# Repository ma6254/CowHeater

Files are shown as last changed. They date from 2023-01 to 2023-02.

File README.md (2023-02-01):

# CowHeater

[[主控板PCB介绍]](pcb_mb/README.md) [[主控板代码介绍]](src_mb/README.md)

CowHeater 是一个开源的加热台，不便携。

目标在于实现一种比较通用的加热器件控制器，
同时学习可控硅控制、热电偶温度采集、PID等电子技术。

- 主控：STC8H8K64U(TSSOP-20)
- 供电方式：ACDC 集成模块
- 控制方式：可控硅斩波调功率
- 温度采集方式：K型热电偶+运放

system block diagram

## 购买元器件

在[立创商城BOM配单](https://bom.szlcsc.com/bom/upload.html)即可，BOM文件位于[docs/BOM_for_LCSC.csv](docs/BOM_for_LCSC.csv)

注意：

- 海凌科的电源模块长期无现货，在淘宝上购买
- 用到的STC单片机长期无现货，在淘宝上购买
- 运放和可控硅尽量在立创商城上买，淘宝假货太多了

## 进度表

1. `2023-01-06` 打算做个加热台的项目
   - PCB_V01 随便拉了线，发去嘉立创打样了
   - 淘宝和立创商城上买了一堆器件
   - 买了某仙子的PTC，后面再搞高温的MCH发热板吧
2. `2023-01-08` 等快递ing
   - BUG: 发热板热量会通过铜柱传导到PCB上面，后面需要解决
   - 靠，立创商城下单数量错了，STC单片机只买了一片
   - 靠，PCB打样的收件地址写错了，写成了上家公司，让同事寄过来了
   - 靠，烧录口没引出来，还得割线飞线
   - 有几个包裹是圆通的，还没配送
3. `2023-01-12` 快递到了，开始调试
   - 可控硅导通不了，R10改为360Ω，增加R13为330Ω
   - 电源模块封装不对，实物整体往右偏1.5mm
4. `2023-02-01` 改了板子，重新发出去打样
   - PCB_V02
   - PCB_V03
   - 电源模块从 `HLK-2M05` 换成了 `HLK-5M05`
   - 干哦，可控硅电路还是没有调通，发现是12脚反了

## 参考资料

### STC开发资料

- STC8H数据手册: <http://www.stcmcudata.com/STC8F-DATASHEET/STC8H.pdf>
  - P.72: STC8H8K64U-TSSOP20引脚定义
- STC-ISP下载链接: <http://www.stcmcudata.com/STCISP/stc-isp-15xx-v6.91I.zip>
- STC命令行烧录软件 stcflash: <https://github.com/sms-wyt/stcflash>

### 海凌科电源模块资料

- [HLK-2M05/2M03/2M09/2M12/2M24 2W系列AC-DC电源模块](<https://www.hlktech.com/Goods-39.html>)
- [海凌科2W系列电源模块说明书V2.6.pdf](http://r0.hlktech.com/download/ACDC%E7%94%B5%E6%BA%90%E6%A8%A1%E5%9D%972W%E7%B3%BB%E5%88%97/1/%E6%B5%B7%E5%87%8C%E7%A7%912W%E7%B3%BB%E5%88%97%E7%94%B5%E6%BA%90%E6%A8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)

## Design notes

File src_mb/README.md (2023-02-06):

# Source CowHeater_MB

芯片: `STC8H8K64U`(`TSSOP20`)

烧录文件: [`Objects/cowheater_mb.hex`](Objects/cowheater_mb.hex)

## 引脚定义

| Name | Pin | GPIO | Description |
| --- | --- | --- | --- |
| LED | 5 | P13 | 测试用的，接LED负极 |
| UART1_RX | 11  | P30/RxD  | STC-ISP烧录口，UART1_RX |
| UART1_TX | 12  | P31/TxD  | STC-ISP烧录口，UART1_TX |
| I2C_SCL  | 2 | P15 | 预留，接I2C器件SCL |
| I2C_SDA  | 1 | P14 | 预留，接I2C器件SDA |
| HEAT | 20  | P10 | 可控硅控制脚 |
| TEMP | 19  | P11/ADC1 | 热床温度，热电偶信号采样脚 |

## 目录

```plaintext
├─.vscode             # VSCode配置
├─Objects             # 编译生成
└─Sources             # 源代码
    ├─app             # 应用层代码
    │  └─main.c       # 程序入口
    ├─components      # 组件库
    │  ├─thermocouple # 热电偶
    │  └─thyristor    # 可控硅
    └─stc_hal         # STC寄存器驱动
```

## 添加STC头文件到Keil中

- 打开STC-ISP，在右侧的选项卡中有个 `Keil仿真设置`
- 点击该按钮，选择keil安装目录，再按确定即可

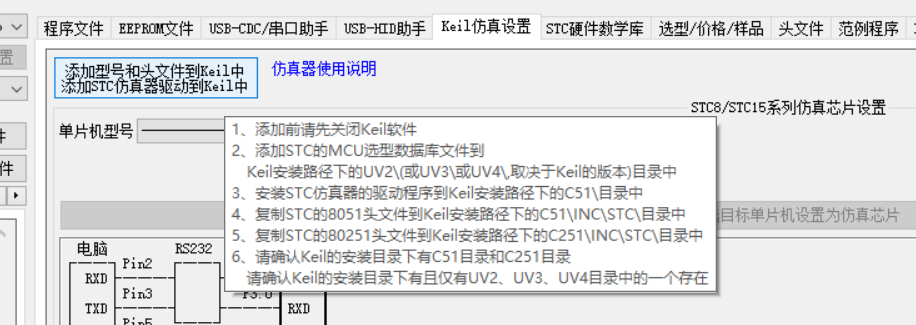
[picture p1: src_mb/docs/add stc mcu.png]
add stc mcu

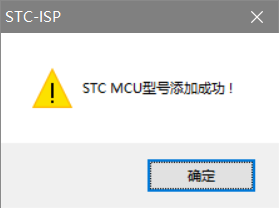
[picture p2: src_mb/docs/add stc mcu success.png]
add stc mcu success


## VSCode的配置文件

[c_cpp_properties.json#L6](./.vscode/c_cpp_properties.json#L6)

`c_cpp_properties.json`中的 `includePath`字段为头文件包含路径，其中指向keil头文件的路径需要改为你电脑上实际的安装路径

例如，我电脑上为：`C:\Keil_v5`，需要将反撇号改为正撇号，再加上一串路径，最后为：`C:/Keil_v5/C51/INC/**`

## 将Keil中的文件编码格式改为GB2312

不论是否发生乱码，请都将keil的编码格式改为GB2312（仅为本项目）

左上角 `Edit`，然后是 `Configuration..`，第一个选项卡 `Editor`

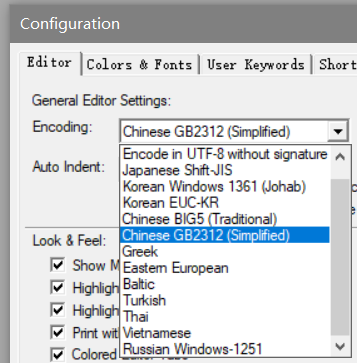
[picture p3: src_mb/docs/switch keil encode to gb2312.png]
switch keil encode to utf8


## 使用stcflash烧录

stcgal不支持stc8h，可以用`sms-wyt`版本的stcflash
在keil中配置好之后，按快捷键`F8`就可以烧录了

keil flash use stcflash
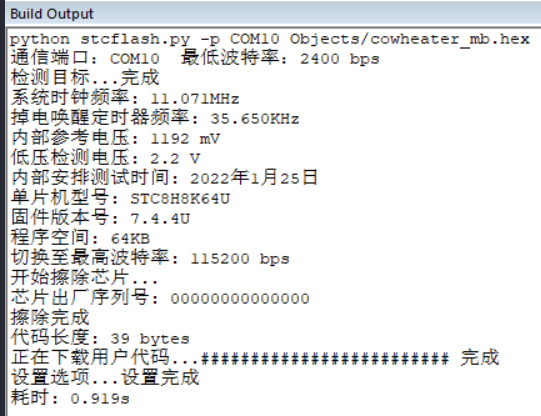
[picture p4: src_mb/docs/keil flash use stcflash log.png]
keil flash use stcflash log

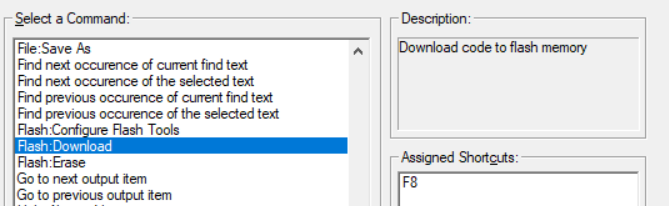
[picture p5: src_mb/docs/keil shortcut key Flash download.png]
keil shortcut key Flash download


## 参考资料

- Keil Configuration Wizard: <https://www.keil.com/pack/doc/CMSIS_Dev/Pack/html/configWizard.html>

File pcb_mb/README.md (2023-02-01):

# PCB CowHeater_MB

主控板AD工程

## 目录

```plaintext
├─Backups              # 版本备份
├─CowHeater_SCH.SchDoc # 原理图
├─CowHeater_PCB.PcbDoc # PCB
├─CowHeater_PCB.PrjPcb # 工程文件
├─PcbLib1.PcbLib       # PCB封装库
└─Schlib1.SchLib       # 原理图封装库
```

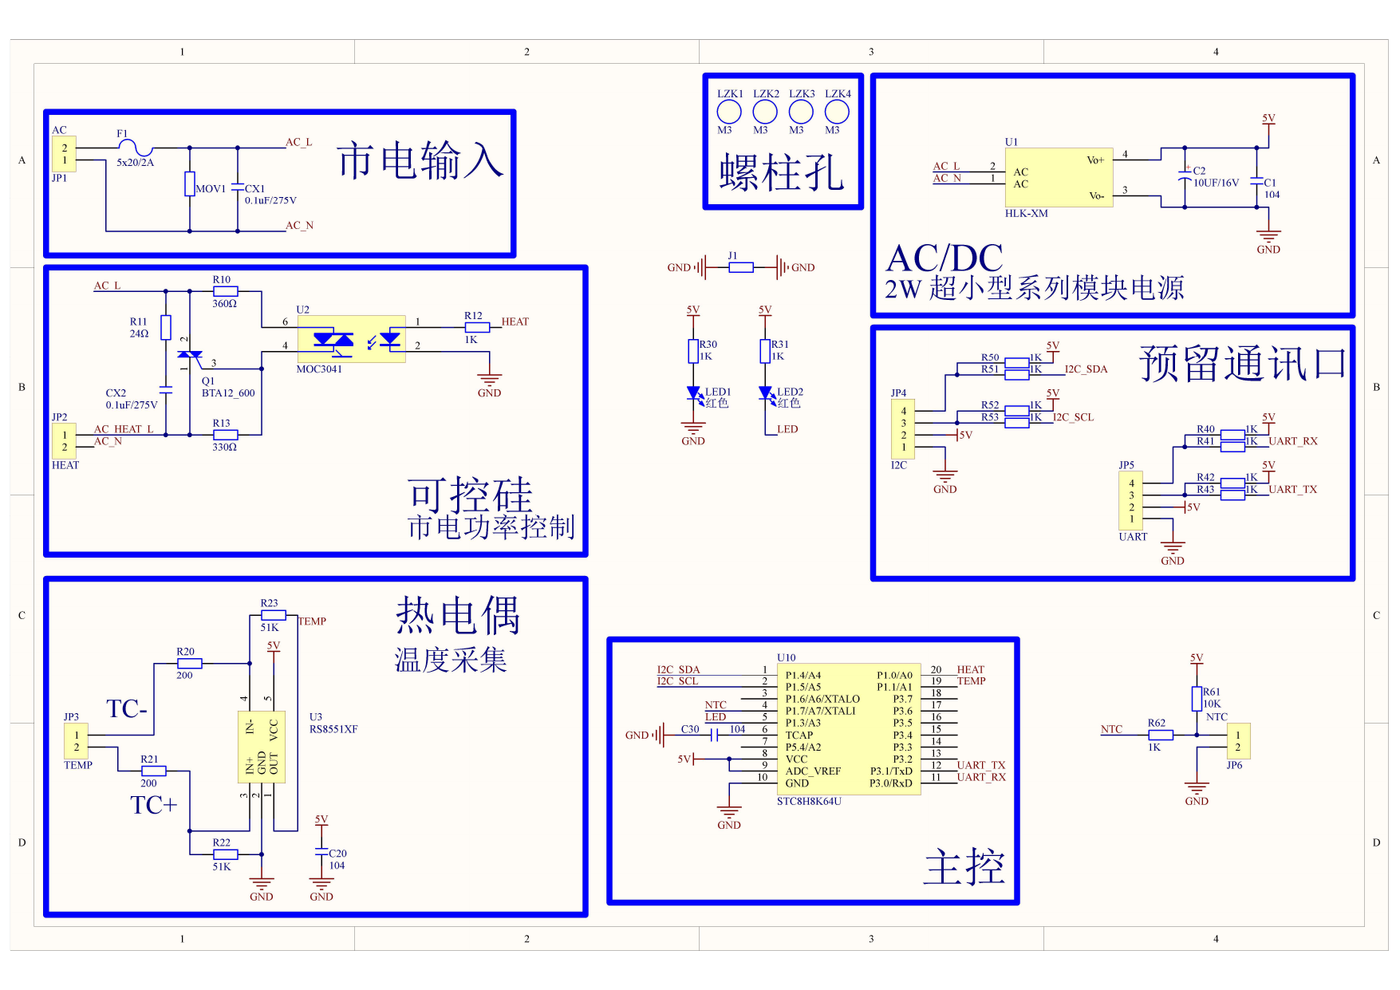
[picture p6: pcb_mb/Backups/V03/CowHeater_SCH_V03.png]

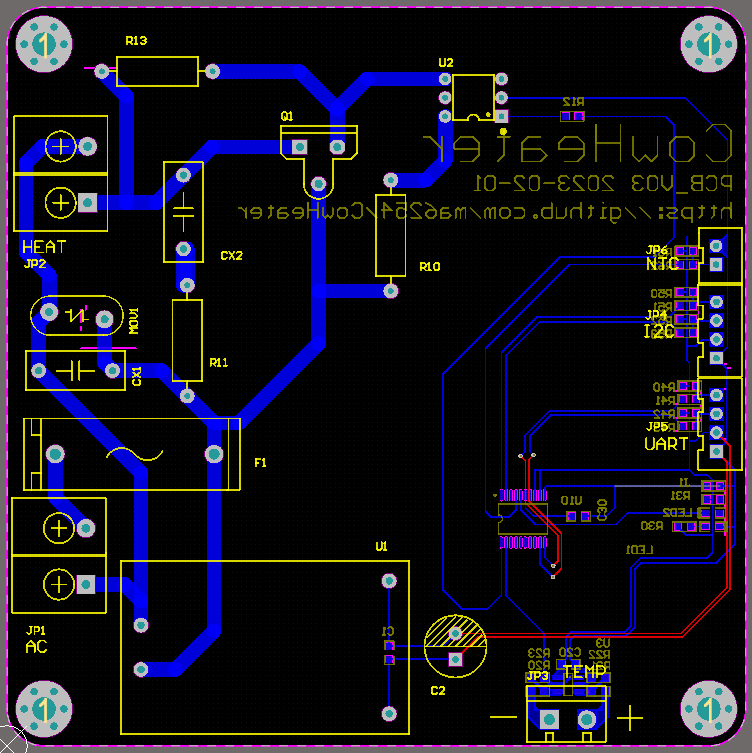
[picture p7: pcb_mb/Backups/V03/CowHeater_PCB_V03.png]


## PDF to img

for windows

```powershell
# 需要先安装scoop
PS> scoop install poppler
```

```powershell
PS> pdftoppm -png .\CowHeater_SCH_V01.pdf CowHeater_SCH_V01
```

## 参考资料

- 常用AD器件库 <https://github.com/Kevincoooool/AltiumDesigner_PcbLibrary_3D>

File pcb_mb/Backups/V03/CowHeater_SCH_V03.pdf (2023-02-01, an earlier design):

# AC/DC

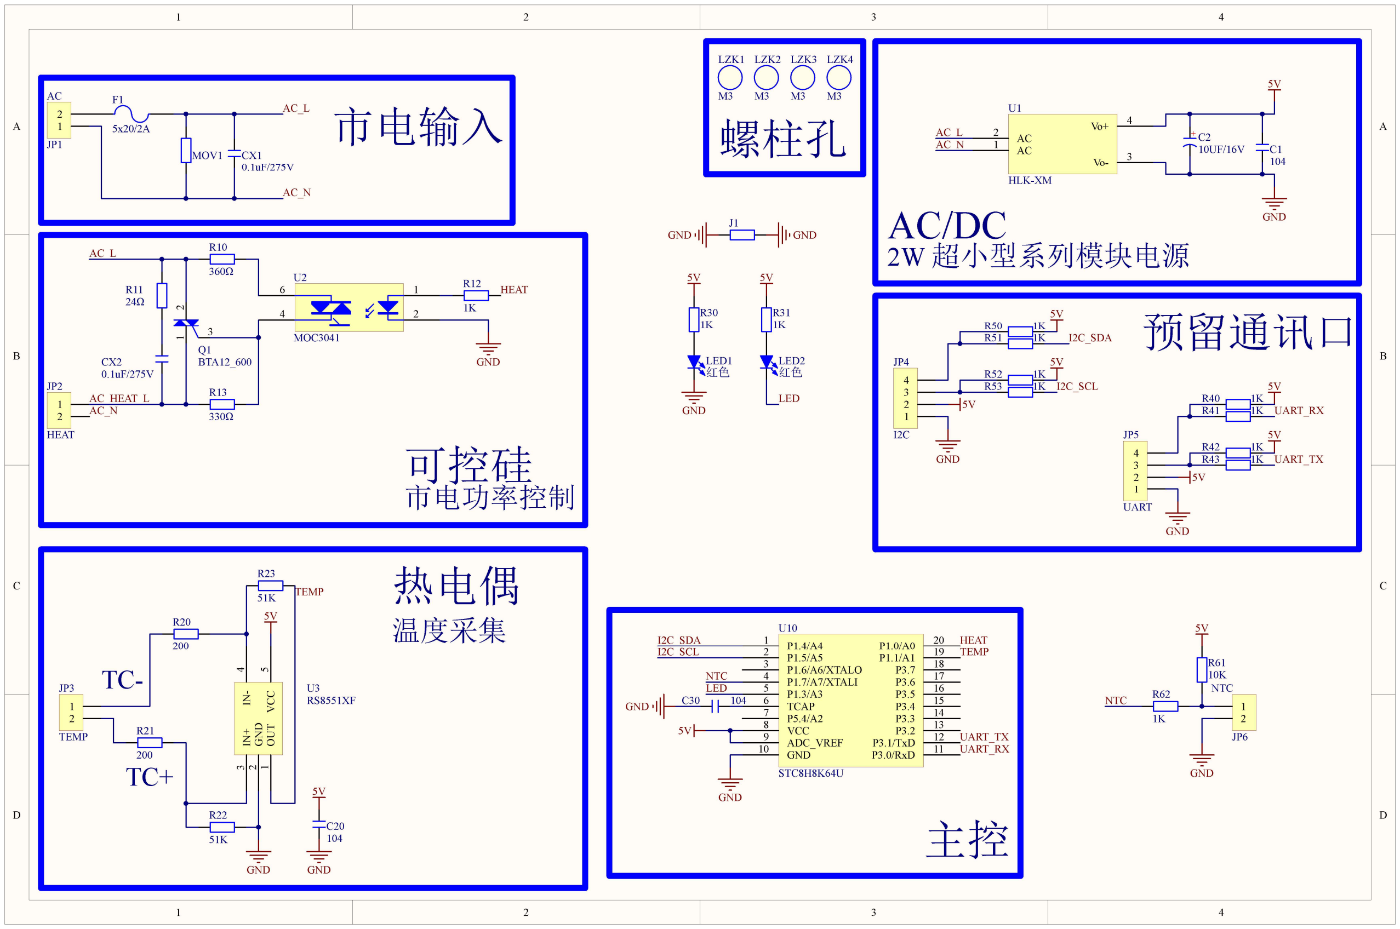
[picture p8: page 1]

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
AC 1

AC 2

Vo- | 3
Vo+ | 4

U1

HLK-XM

1

2

JP1

AC

GND

5V
F1

5x20/2A

AC_N

# 2W 超小型系列模块电源

1
2

JP2

HEAT | 2 1

3
Q1
BTA12_600

# 可控硅 市电功率控制

AC_L

GND

R10

360Ω
HEAT R12

1K

R11
24Ω

CX2
0.1uF/275V

CX1
0.1uF/275V

AC_L

MOV1

LZK1

M3

LZK2

M3

LZK3

M3

LZK4

M3

1
2

JP3

TEMP

# 热电偶

# 温度采集 OUT

## 1 GND

## 2 IN+

# 3 IN- 4 VCC

5
U3
RS8551XF

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
104 ⁺

C2 市电输入 | 螺柱孔 | 10UF/16V

TEMP

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
I2C_SCL

I2C_SDA

1

2

3

4

JP5

UART

GND

5V

# 预留通讯口

P1.4/A4 1
P1.5/A5 2
P1.6/A6/XTALO 3
P1.7/A7/XTALI 4
P1.3/A3 5
TCAP 6
P5.4/A2 7
VCC 8
ADC_VREF 9
GND 10 | P3.0/RxD | 11 P3.1/TxD | 12 P3.2 | 13 P3.3 | 14 P3.4 | 15 P3.5 | 16 P3.6 | 17 P3.7 | 18 P1.1/A1 | 19 P1.0/A0 | 20

U10

STC8H8K64U

1

4 2

6

U2

MOC3041

5V

GND

TEMP

I2C_SDA
I2C_SCL

主控

C30 104 GND

R30
1K

LED1
红色

5V

GND

R31
1K

LED2
红色

5V

LED
R41 | 1K
R43 | 1K
R40 | 1K

5V

R42 1K

5V

R51 | 1K
R53 | 1K
R50 | 1K
R52 | 1K

5V

5V

HEAT

UART_TX

UART_RX

LED

J1
GND | GND

UART_RX

UART_TX

R13

330Ω

AC_HEAT_L
AC_N

AC_N

AC_L

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
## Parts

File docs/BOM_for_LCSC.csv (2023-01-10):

No | 名称 | 型号/规格 | 封装 | 用量 | 品牌 | 商品编号 | 备注
0 | 占位 |  |  |  |  |  | 立创商城只支持GBK格式，切勿用UTF8格式保存该文件
1 | ACDC | HLK-2M05 | 插件 | 1 | HI-LINK(海凌科) | C209909 | 好贵，淘宝走起
2 | 单片机 | STC8H8K64U | TSSOP-20 | 1 | STC(宏晶) | C5210758 | 需要订货，淘宝走起
3 | 线对板/线对线连接器 | XH 2.5mm 1x4P | 插件,P=2.5mm | 2
4 | 栅栏式接线端子 | KF7.62-2P | 插件,P=7.62mm | 2
5 | 保险丝座(盒) | 5x20 BLX-A型 保险丝支架 XC-7 | 插件 | 1 | xcfuse(旭程) | C3131
6 | 螺钉式接线端子 | KF301-5.0-2P | 插件,P=5mm | 1 |  |  | 好贵，淘宝走起
7 | 精密运放 | RS8551XF | SOT-23-5 | 1 | RUNIC(润石) | C237000
8 | 光耦-可控硅信号输出 | 3041 | DIP-6 | 1

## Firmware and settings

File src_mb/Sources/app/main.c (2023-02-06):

#include <stdio.h>
#include <STC8H.h>

#include "stc_hal_config.h"
#include "hal_sys.h"
#include "board.h"
#include "hal_gpio.h"
#include "hal_timer.h"
#include "hal_adc.h"
#include "hal_uart.h"
#include "hal_config_msg.h"

#include "load.h"
#include "sensor.h"

/*******************************************************************************
 * @brief GPIO初始化
 * @param None
 * @return None
 ******************************************************************************/
void sys_gpio_init(void)
{
    // gpio_t tmp_gpio;

    // hal_gpio_struct_default(&tmp_gpio);
    // tmp_gpio.port = LED_GPIO_PORT;
    // tmp_gpio.xbit = LED_GPIO_BIT;
    // tmp_gpio.mode = gpio_mode_output;
    // hal_gpio_config_apply(&tmp_gpio);

    // hal_gpio_struct_default(&tmp_gpio);
    // tmp_gpio.port = HEAT_GPIO_PORT;
    // tmp_gpio.xbit = HEAT_GPIO_BIT;
    // tmp_gpio.mode = gpio_mode_output;
    // hal_gpio_config_apply(&tmp_gpio);

    Init_IO_Out_L(LED_GPIO_PORT, LED_GPIO_BIT);
    Init_IO_Out_L(HEAT_GPIO_PORT, HEAT_GPIO_BIT);

    Init_IO_Out_H(3, 1);
    Init_IO_In_Up(3, 0);

    Init_IO_In_NoUp(TEMP_GPIO_PORT, TEMP_GPIO_BIT);
    IO_Out_H(TEMP_GPIO_PORT, TEMP_GPIO_BIT);
    P1IE &= ~B0000_0010;

    Init_IO_In_NoUp(NTC_GPIO_PORT, NTC_GPIO_BIT);
    IO_Out_H(NTC_GPIO_PORT, NTC_GPIO_BIT);
    P1IE &= ~B1000_0000;
}

/*******************************************************************************
 * @brief 初始化
 * @param None
 * @return None
 ******************************************************************************/
void sys_init(void)
{
    /***************************************************************************
     * 外设初始化
     **************************************************************************/
    En_XFR();
    sys_gpio_init();
    hal_timer2_init(1000);
    // UartInit();
    hal_uart1_init(115200, HAL_UART1_IOMUX_P30_P31);
    hal_adc_init();

    /***************************************************************************
     * 组件初始化
     **************************************************************************/
    gload_init();

    /***************************************************************************
     * 上电初始化流程
     **************************************************************************/
    hal_allow_all_interrupt();
    // Delay_PowerUp();
}

#define TARGET_TEMP ((int16_t)800)

data uint32_t hello_led_tmp_time = 0;

BOOL zn_old_status;
data uint32_t zn_last_time = 0;
data uint32_t zn_time = 0;
int16_t zn_max_tmp_temp = 0;
int16_t zn_min_tmp_temp = 0;
int16_t zn_max_temp = 0;
int16_t zn_min_temp = 0x7FFF;

/*******************************************************************************
 * @brief 主函数，程序入口
 * @param None
 * @return None
 ******************************************************************************/
void main(void)
{
    hal_init();
    sys_init();
    while (1)
    {

        if (hal_delay_ms(&hello_led_tmp_time, 250))
        {
            IO_Out_Flip(1, 3);
        }

        // if (hal_delay_ms(&aaa_tmp_time, 1000))
        // {
        //     if (G_LOAD.triac.duty)
        //         G_LOAD.triac.duty = 0;
        //     else
        //         G_LOAD.triac.duty = 10;

        //     if (heat_temp_filt.Result > TARGET_TEMP)
        //     {
        //         G_LOAD.triac.duty = 0;

        //         if (zn_old_status == TRUE)
        //         {
        //             zn_time = hal_uptime - zn_last_time;
        //             zn_last_time = hal_uptime;

        //             zn_max_temp = zn_max_tmp_temp;
        //             zn_min_temp = zn_min_tmp_temp;
        //             zn_max_tmp_temp = 0;
        //             zn_min_tmp_temp = 0x7FFF;
        //         }
        //         zn_old_status = FALSE;
        //     }
        //     else
        //     {
        //         G_LOAD.triac.duty = 10;
        //         zn_old_status = TRUE;
        //     }
        // }

        sensor_task();
        load_task();
        debug_print_task();
    }
}

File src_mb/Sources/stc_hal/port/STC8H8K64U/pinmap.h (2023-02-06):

#ifndef PINMAP_H
#define PINMAP_H

#include "model_meta.h"
#include "port/STC8H/pinmap.h"

#if CHIP_FOOTPRINT == CHIP_FOOTPRINT_LQFP64

// analog port
#define AN_NUM 15
#define GPIO_AN0 GPIO_P10  // 4'b0000 P1.0 / ADC0
#define GPIO_AN1 GPIO_P11  // 4'b0001 P1.1 / ADC1
#define GPIO_AN2 GPIO_P54  // 4'b0010 P5.4 / ADC2
#define GPIO_AN3 GPIO_P13  // 4'b0011 P1.3 / ADC3
#define GPIO_AN4 GPIO_P14  // 4'b0100 P1.4 / ADC4
#define GPIO_AN5 GPIO_P15  // 4'b0101 P1.5 / ADC5
#define GPIO_AN6 GPIO_P16  // 4'b0110 P1.6 / ADC6
#define GPIO_AN7 GPIO_P17  // 4'b0111 P1.7 / ADC7
#define GPIO_AN8 GPIO_P00  // 4'b1000 P0.0 / ADC8
#define GPIO_AN9 GPIO_P01  // 4'b1001 P0.1 / ADC9
#define GPIO_AN10 GPIO_P02 // 4'b1010 P10.2/ ADC10
#define GPIO_AN11 GPIO_P03 // 4'b1011 P10.3/ ADC11
#define GPIO_AN12 GPIO_P04 // 4'b1100 P10.4/ ADC12
#define GPIO_AN13 GPIO_P05 // 4'b1101 P10.5/ ADC13
#define GPIO_AN14 GPIO_P06 // 4'b1110 P10.6/ ADC14
// 4'b1111 inte 1.19V

#define AN_P10 0
#define AN_P11 1
#define AN_P54 2
#define AN_P13 3
#define AN_P14 4
#define AN_P15 5
#define AN_P16 6
#define AN_P17 7
#define AN_P00 8
#define AN_P01 9
#define AN_P02 10
#define AN_P03 11
#define AN_P04 12
#define AN_P05 13
#define AN_P06 14
#define AN_INTE119 15

#elif CHIP_FOOTPRINT == CHIP_FOOTPRINT_TSSOP20 /* End of CHIP_FOOTPRINT_LQFT64 */

/*******************************************************************************
 *
 * gpio define
 * 普通IO口定义
 *
 ******************************************************************************/

#define GPIO_NUM 16 // 总计普通IO数量

// left side
// 左侧列
#define GPIO_P14 14 // SDA/MISO/PWM3P/ADC4/P1.4
#define GPIO_P15 15 // SCL/SCLK/PWM3N/ADC5/P1.5
#define GPIO_P16 16 //
#define GPIO_P17 17 //
#define GPIO_P13 13 //
// UCap
#define GPIO_P54 54 // T2/ADC2/PWM6_2/PWM2P/SS_3/SS/MCLKO/NRST/PWM6_2/P5.4
// Vcc/AVcc
// Gnd/AGnd

// right side
// 右侧列
#define GPIO_P10 10 // P1.0/ADC0/RxD2/PWM1P
#define GPIO_P11 11 // P1.1/ADC1/TxD2/PWM1N
#define GPIO_P37 37 // P3.7/INT3/TxD_2/CMP+
#define GPIO_P36 36 // P3.6/INT2/RxD_2/CMP-
#define GPIO_P35 35 // P3.5/T1/T0CLKO/SS_4/PWMFLT/PWMFLT2
#define GPIO_P34 34 // P3.4/T0/T1CLKO/MOSI_4/PWM4P_4/PWM8_2/CMPO
#define GPIO_P33 33 // P3.3/INT1/MISO_4/I2CSDA_4/PWM4N_4/PWM7_2
#define GPIO_P32 32 // P3.2/INT0/SCLK_4/I2CSCL_4/PWMETI/PWMETI2
#define GPIO_P31 31 // P3.1/TxD/D+
#define GPIO_P30 30 // P3.0/RxD/D-/INT4

/*******************************************************************************
 *
 * analog port define
 * 模拟口定义
 *
 ******************************************************************************/

#define AD_NUM 7          // 总计ADC口数量

// analog port
#define GPIO_AD0 GPIO_P10 // 4'b0000 P1.0 / ADC0
#define GPIO_AD1 GPIO_P11 // 4'b0001 P1.1 / ADC1
#define GPIO_AD3 GPIO_P13 // 4'b0011 P1.3 / ADC3
#define GPIO_AD4 GPIO_P14 // 4'b0100 P1.4 / ADC4
#define GPIO_AD5 GPIO_P15 // 4'b0101 P1.5 / ADC5
#define GPIO_AD6 GPIO_P16 // 4'b0110 P1.6 / ADC6
#define GPIO_AD7 GPIO_P17 // 4'b0111 P1.7 / ADC7

// GPIO转ADC通道
#define AN_P10 ADC_CH0
#define AN_P11 ADC_CH1
#define AN_P13 ADC_CH3
#define AN_P14 ADC_CH4
#define AN_P15 ADC_CH5
#define AN_P16 ADC_CH6
#define AN_P17 ADC_CH7

#else /* End of CHIP_FOOTPRINT_TSSOP20 */
#error "Unknown CHIP_FOOTPRINT"
#endif /* End of Unknown CHIP_FOOTPRINT */

#endif /* End of PINMAP_H */

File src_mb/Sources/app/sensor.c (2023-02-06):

#include "sensor.h"

#include "hal_timer.h"
#include "hal_adc.h"

#define SENSOR_TASK_TIME ((time_t)10)

sensor_t gSensor;
data uint32_t sensor_task_tmp_time = 0;

struct Slide_Filter heat_temp_filt;

void sensor_task(void)
{
    static int16_t tmp_i16 = 0;

    if (hal_delay_ms(&sensor_task_tmp_time, SENSOR_TASK_TIME))
    {
        gSensor.raw_adc_tc = hal_adc_read(HAL_ADC_CH1);
        gSensor.raw_adc_ntc = hal_adc_read(HAL_ADC_CH7);
        gSensor.raw_adc_inte = hal_adc_read(HAL_ADC_V119);

        // NTC温度换算
        if (gSensor.raw_adc_ntc > 3325)
            tmp_i16 = -100;
        else if (gSensor.raw_adc_ntc < 1508)
            tmp_i16 = 400;
        else
            tmp_i16 = 400 - (gSensor.raw_adc_ntc - 1508) / 3.634;
        gSensor.ntc_temp = tmp_i16;

        // 热电偶温度换算
        tmp_i16 = (int32_t)(gSensor.ntc_temp) +
                  (int32_t)(gSensor.raw_adc_tc) * 100 / 41;
        gSensor.heat_temp = Slide_Filter_Push(&heat_temp_filt, 32, tmp_i16);
    }
}

/*******************************************************************************
 * @brief 滑动滤波
 * @param s 滤波结构体
 * @param Filt_Cnt 滤波次数
 * @param val 输入值
 * @return None
 ******************************************************************************/
uint16_t Slide_Filter_Push(struct Slide_Filter *s, uint8_t Filt_Cnt, uint16_t val)
{
    uint8_t i = 0;
    uint32_t sum = 0;
    uint8_t max_index = 0, min_index = 0;

    s->Array[s->P] = val;
    s->P++;
    s->P %= Filt_Cnt;

    if (s->C < Filt_Cnt)
    {
        s->C++;
        s->Result = val;
        return val;
    }

    // 求平均时滤除最大值和最小值
    for (i = 1; i < Filt_Cnt; i++)
    {
        if (s->Array[i] < s->Array[min_index])
        {
            min_index = i;
        }
        if (s->Array[i] > s->Array[max_index])
        {
            max_index = i;
        }
    }

    for (i = 0; i < Filt_Cnt; i++)
    {
        if ((i == max_index) || (i == min_index))
            continue;
        sum += s->Array[i];
    }

    if (max_index == min_index)
        s->Result = sum / (Filt_Cnt - 1);
    else
        s->Result = sum / (Filt_Cnt - 2);

    return s->Result;
}

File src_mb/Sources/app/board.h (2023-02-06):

#ifndef BOARD_H
#define BOARD_H

#include "hal_sys.h"

// 调试用LED
// P13
#define LED_GPIO_PORT 1
#define LED_GPIO_BIT 3

// 可控硅光耦控制
// P10
#define HEAT_GPIO_PORT GPIO_P1
#define HEAT_GPIO_BIT 0

// 加热板温度，热电偶信号采样
// P11
#define TEMP_GPIO_PORT GPIO_P1
#define TEMP_GPIO_BIT 1

// 冷端温度
// P17
#define NTC_GPIO_PORT GPIO_P1
#define NTC_GPIO_BIT 7

#endif /* End of BOARD_H */

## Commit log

2023-01-10 init repo, pcb_v01
    [BOM_for_LCSC.csv, CowHeater_PCB.PrjPcb, CowHeater_SCH.SchDoc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]
2023-01-10 update bom to beautify
    [BOM_for_LCSC.csv]
2023-01-10 FEAT: update BOM, update README
    [BOM_for_LCSC.csv]
2023-01-15 UPDATE: add R13, changge uart port
    [CowHeater_PCB.PrjPcb, CowHeater_SCH.SchDoc, PcbLib1.PcbLib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]
2023-02-01 UPDATE: pcb_v03
    [CowHeater_PCB.PrjPcb, CowHeater_SCH.SchDoc, PcbLib1.PcbLib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]
2023-02-06 feat: ntc, tc, triac, pid
    [CowHeater_SCH.SchDoc]
